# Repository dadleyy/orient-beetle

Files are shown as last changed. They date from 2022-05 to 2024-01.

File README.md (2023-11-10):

# Orient-Beetle

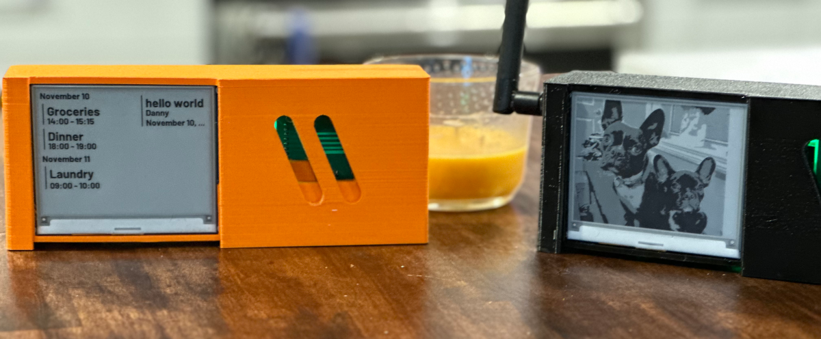
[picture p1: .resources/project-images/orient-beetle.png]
orient-beetle


A project that incorporates a wifi-enabled microcontroller, an e-ink display and some nice
RGB LEDs.

For general platform architecture documentation, see [`.docs/architecture.md`][arch].

For the hardware bill of materials, see [`.docs/hardware.md`][bom]

## Beetle PIO (Firmware)

The firmware for the application lives in [`src/beetle-pio`][fm-rd] and can be compiled
using the [platformIO cli][pio]. 

### Environment Setup: Redis Environment Variables

The firmware relies on compile-time configuration information to determine what server,
port, and authentication information to use when establishing it's secure connection to
your redis instance. The most straightforward way to set this up is to define a `.env`
file at the root of the `beetle-io` platformio application:

```
$ cat ./src/beetle-io/.env

REDIS_PORT=1234
REDIS_HOST="my-redis.my-host.com"
REDIS_AUTH_USERNAME="orient-beetle-device-id-consumer"
REDIS_AUTH_PASSWORD="1bc2ad"
```

This file is read by the [`extra_scripts`][extra_scripts] entry [`load_env.py`][lenv] and will
automatically attempt to set the correct `-DREDIS_HOST`, `-DREDIS_PORT`, and auth compiler flags.

The values of the `REDIS_AUTH_USERNAME` and `REDIS_AUTH_PASSWORD` values
require successfully "provisioning" your environment (more on this in the
[`srv` documentation](#beetle-srv-(web-backend)) below).

### Environment Setup: Redis Host CA Certificate

In order for the esp32 module to connect over tls to your redis host, you will need
to download the root ca certificate for the host and save it to:

```
src/beetle-pio/embeds/redis_host_root_ca.pem
```

The contents of this file are loaded into flash memory via the
`board_build.embed_txtfiles` setting defined in the project's `platform.ini`
file.

_For more information on how to prepare the ssl/tls components for our redis
connection, refer to [`.docs/redis-help.md`](.docs/redis-help.md)_.

### Compiling With `pio`

Once your environment and certificate file have been prepared, the firmware can
be compiled from the `beetle-pio` directory:

```
$ cd src/beetle-pio
$ pio run -t upload             <- will attempt to compile + upload to device
$ pio run -t upload -e release  <- builds without Serial logs
```

### Hardware & Documentation

For a list of harware involved and other documentation, see [`.docs/README.md`](/.docs/README.md).

#### Troubleshooting with `src/beetle-pio-tls-tester`

It can be ticky to know which certificate is required for a valid connection over tls with
your hosted redis provider. To help validate your certificate, the
[`src/beetle-pio-tls-tester`](./src/beetle-pio-tls-tester) directory contains a platformio
project can can be flashed onto your ESP32 to verify.

This project uses a very similar to configuration to the main `beetle-pio` project; you are
expected to provide both a `.env` file and `embeds/redis_host_root_ca.pem` file. If your
certificate file is valid, you should see something like:

```
[  4353][V][ssl_client.cpp:59] start_ssl_client(): Free internal heap before TLS 225035
[  4361][V][ssl_client.cpp:65] start_ssl_client(): Starting socket
[  4707][V][ssl_client.cpp:141] start_ssl_client(): Seeding the random number generator
[  4709][V][ssl_client.cpp:150] start_ssl_client(): Setting up the SSL/TLS structure...
[  4712][V][ssl_client.cpp:166] start_ssl_client(): Loading CA cert
[  4782][V][ssl_client.cpp:234] start_ssl_client(): Setting hostname for TLS session...
[  4783][V][ssl_client.cpp:249] start_ssl_client(): Performing the SSL/TLS handshake...
[  6214][V][ssl_client.cpp:270] start_ssl_client(): Verifying peer X.509 certificate...
[  6215][V][ssl_client.cpp:279] start_ssl_client(): Certificate verified.
[  6218][V][ssl_client.cpp:294] start_ssl_client(): Free internal heap after TLS 177751
[  6226][D][main.cpp:26] loop(): connection result: 1
[  7231][D][main.cpp:18] loop(): connected: 1
```

This assumes you have compiled and uploaded via `pio`:

```
$ pio run -t upload
$ screen /dev/ttyUSB0 115200
```

----

## Beetle SRV (Web Backend)

There are several rust exectuables that live in the [`srv/beetle-srv`](./src/beetle-srv/README.md)
directory. This includes the http api, a dirty little cli for troubleshooting, and a background worker
responsible for applying logic based on device connections. These applications generally require
an `env.toml` file with the various secrets that will be used for redis, mongo, etc... An example 
file can be seen at [`src/beetle-src/env.example.toml`](src/beetle-srv/env.example.toml)

For more detailed instructions for hosting your own instance, refer to [`.docs/hosting.md`](./.docs/hosting.md).

### Creating Redis ACL for all devices

As part of provisioning your environment, you will need to create the appropriate redis acl entry that
will be flashed onto all devices and should only be able to `pop` ids off our registrar index:

```
$ cd src/beetle-srv
$ cargo run cli provision orient-beetle-id-consumer abc1234
```

----

## Beetle UI (Web Frontend)

The web ui for this project can be found in the [`src/beetle-ui`](./src/beetle-ui/README.md) directory.

----

## Miscellaneous Tools

1. [WiFi Configuration HTML Generator][wchgen] - This tiny rust application is used to generate the
contents of the `src/beetle-pio/embed/index.html` file from an `index.html` file input.

--- 

## Nice Third Party Providers for Services Used At Runtime

- redis @ [upstash](https://upstash.com/) - supports tls _and_ `ACL` command management. not really free.
- mongo @ [cloud.mongodb.com](https://cloud.mongodb.com) - has a free tier for hosted mongodb databases/clusters.
- oauth @ [auth0](https://manage.auth0.com) - has a free tier for managing your login page.

---

This project was named by combining the name of the development board (fire<i>beetle</i>) with the name of
the manufacturer of the display being used (_orient_ displays).

[pio]: https://docs.platformio.org/en/stable/core/index.html
[dotenv]: https://github.com/ohmyzsh/ohmyzsh/blob/master/plugins/dotenv/dotenv.plugin.zsh
[wchgen]: ./tools/wchgen/README.md
[extra_scripts]: https://docs.platformio.org/en/latest/scripting/actions.html
[lenv]: ./src/beetle-pio/load_env.py
[fm-rd]: ./src/beetle-pio/README.md
[arch]: ./.docs/architecture.md
[bom]: ./.docs/hardware.md

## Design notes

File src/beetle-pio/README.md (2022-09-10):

# Orient-Beetle Firmware

This is the [platformio]-based project with the source code for the firmware
that runs on the [firebeetle] microcontroller board.

## Generating Fonts

The fonts used by the firmware have been "compiled" down from `.ttf` files
into lvgl-specific header files using the [fontconverter] tool provided by
the maintainers of that framework.

A mapping of characters to icons can be found in the [`mapping.md`][mm] file
located in the `.resources/Glyphter-font` directory at the root of this repo.
 
## Helpful Links

1. [ESP32 Arduino Core][esp32-arduino-core]
1. [lvgl][lvgl]
2. [`lib/README`](./lib/README.md)
2. [`include/README`](./include/README.md)

[← README](../../README.md)

[platformio]: https://platformio.org
[firebeetle]: https://www.dfrobot.com/product-2195.html
[esp32-arduino-core]: https://github.com/espressif/arduino-esp32/tree/master/libraries
[mm]: ../../.resources/Glyphter-font/mapping.md
[fontconverter]: https://lvgl.io/tools/fontconverter
[lvgl]: https://docs.lvgl.io/8/

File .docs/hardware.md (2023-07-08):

### Rev. 2

| name | manufacturer | price | docs |
| ---- | ---- | ---- | --- |
| Xiao ESP32C3 | Seeed Studios | [~$5 (@ digikey.com)][xiao-digi] | [wiki][xiao-wiki] |
| 4.2" E-Ink Display | Orient Displays | [~$35 (@ amazon.com)][xiao-display-amzn] | |
| ws2812b led | | [~$20 (@ amazon.com)][led-amzn] (partial strip use) | |
| lipo battery | | [4 pack ~$40 (@ amazon.com)][lip-amzn] (~$10 each) |
| antenna | | [2 pack ~$9 (@ amazon.com)][antenna-amzn] (~$4.50 each) |

> Note: the rev. 2 pcb "shield" schematic and board files can be found in the [`/hardware`](../hardware)
> directory. These were created in Eagle.

#### Xiao ESP32-C3 Soldering

The xiao-esp32c3 does include a battery charge chip, but the connections are not exposed as pin
through holes; they are surface pads on the bottom of the chip, marked by the `BAT` label:

| :camera: |
| --- |
|  |

To use the lipo battery, JST cables like [these (amazon link)][jst-amzn] can be soldered to them,
making sure to match the polarity correctly (typically, red to `+`, black to `-`).

---

### Rev. 1*

| name | manufacturer | price | docs |
| ---- | ---- | ---- | --- |
| Firebeetle 2 | DFRobot | [~$8 (@ digikey.com)][beetle] | [wiki][beetle-wiki] |
| 2.4" TFT Display | Orient Displays | [~$14 (@ digikey.com)][display] | [datasheet][display-sheet] |
| VCNL4010 Sensor | Adafruit | [~$8 (@ adafruit.com)][sensor] | [wiki][sensor-wiki] |

> The architecure was overhauled in May 2023 (`v0.1.0`), with the responsibility of rendering messages
> moved from the device into the `srv-*` related appications. The firmware has not been updated to 
> reflect these changes.

##### Rev 1: Pinout

| display pin | firebeetle pin | notes |
| ---- | --- | --- |
| GND | GND | |
| VIN | 3V3 | |
| SCL | SCK |  |
| SDA | MOSI | |
| RST | D12 | this is pin `4` when using `digitalWrite(...)` |
| DC | D11 | this is pin `16` when using `digitalWrite(...)` |
| CS | D10 | this is pin `7` when using `digitalWrite(...)` |
| BLK | D7 | this is pin `13` when using `digitalWrite(...)` |

---

[← README](./README.md)

[display]: https://www.digikey.com/en/products/detail/orient-display/AFL240320A0-2-4N12NTM-ANO/13916615
[beetle]: https://www.digikey.com/en/products/detail/dfrobot/DFR0654/13978504
[beetle-wiki]: https://wiki.dfrobot.com/FireBeetle_Board_ESP32_E_SKU_DFR0654
[display-sheet]: https://www.orientdisplay.com/wp-content/uploads/2021/02/AFL240320A0-2.4N12NTM-ANO.pdf
[sensor]: https://www.adafruit.com/product/466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
[sensor-wiki]: https://learn.adafruit.com/using-vcnl4010-proximity-sensor
[xiao-digi]: https://www.digikey.com/en/products/detail/seeed-technology-co-ltd/113991054/16652880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
[xiao-wiki]: https://www.seeedstudio.com/Seeed-XIAO-ESP32C3-p-5431.html
[xiao-display-amzn]: https://www.amazon.com/dp/B074NR1SW2
[led-amzn]: https://www.amazon.com/gp/product/B088BPGMXB
[lip-amzn]: https://www.amazon.com/gp/product/B095YB8CJK
[antenna-amzn]: https://www.amazon.com/gp/product/B01KBU61S8
[jst-amzn]: https://www.amazon.com/dp/B07FP2FCYC

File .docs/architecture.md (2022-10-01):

# General Platform Architecture

At a high level, the architecture of the platform is based on four components - a web backend,
a web frontend, and the individual devices, with a redis database being leveraged as a message
broker and authentication system for the devices:

general-architecture

### Device Authorization

In order for devices to receive messages, they must first authenticate with the redis service,
which is what we're using to act as a message broker. This authentication scheme is handled by
using redis ACL entries, with a global provisioning ACL burned into devices during firmware
flashing.

```mermaid
sequenceDiagram
    Embedded Device->>Redis: AUTH <burn-in-acl>
    Redis-->>Embedded Device: +OK
    Embedded Device->>Redis: LPOP available_ids
    Redis-->>Embedded Device: 4af2bbd1
    Embedded Device->>Redis: AUTH 4af2bbd1
    Redis-->>Embedded Device: +OK
    note over Embedded Device,Redis: authorized for LPOP
    loop Every Second
        Embedded Device->>Redis: LPOP messages:4af2bbd1
        Redis-->>Embedded Device: <state-message>
    end
```

[← README](../../README.md)

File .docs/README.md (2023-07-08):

### Documentation

1. [Architecture](./architecture.md) - A general outline of the platform architecture.
1. [Hardware Information](./hardware.md) - Bill of materials + general hardware preparation.
1. [Hosting Information](./hosting.md) - Instructions for hosting the rust cloud platform.
1. [Redis Configuration](./redis-help.md) -  Redis FAQ for the `beetle-pio` firmware.

[← README](../README.md)

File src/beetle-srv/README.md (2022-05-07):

## Beetle SRV

This directory contains the [rust] applications for this project.

[← README](../../README.md)

[rust]: https://www.rust-lang.org/

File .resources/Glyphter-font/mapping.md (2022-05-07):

### Font → Icon Mapping

| Character | Icon |
| --- | --- |
| `A` | up arrow |
| `B` | right arrow |
| `C` | down arrow |
| `D` | left arrow |
| `E` | right chevron |
| `F` | info i |
| `G` | info i triangle |
| `H` | thumbtack |
| `I` | checkmark |
| `J` | wifi |
| `K` | person |
| `L` | star |
| `M` | `@` sign |
| `N` | message bubble |
| `O` | plane |
| `P` | calendar |

[← README](../../README.md)

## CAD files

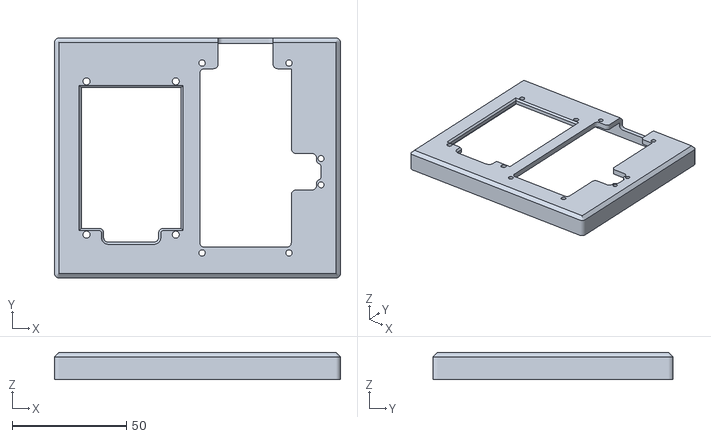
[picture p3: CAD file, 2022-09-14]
hardware/stl/main-case-body.stl
125.0 x 105.0 x 12.0

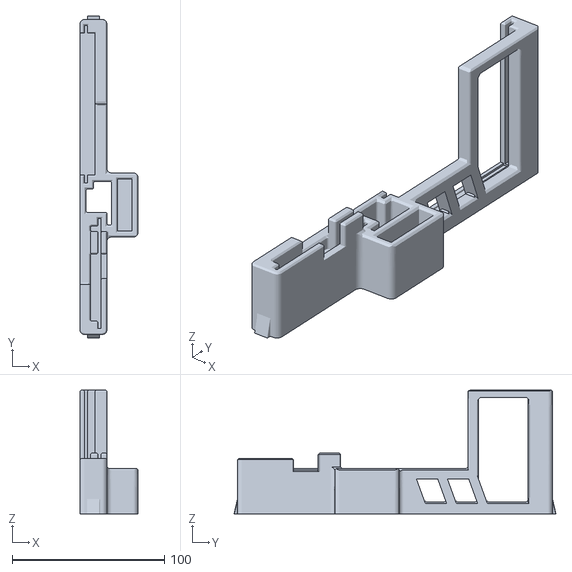
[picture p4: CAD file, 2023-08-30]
hardware/stl/xiao-insert-v85.stl
38.1 x 211.6 x 81.5

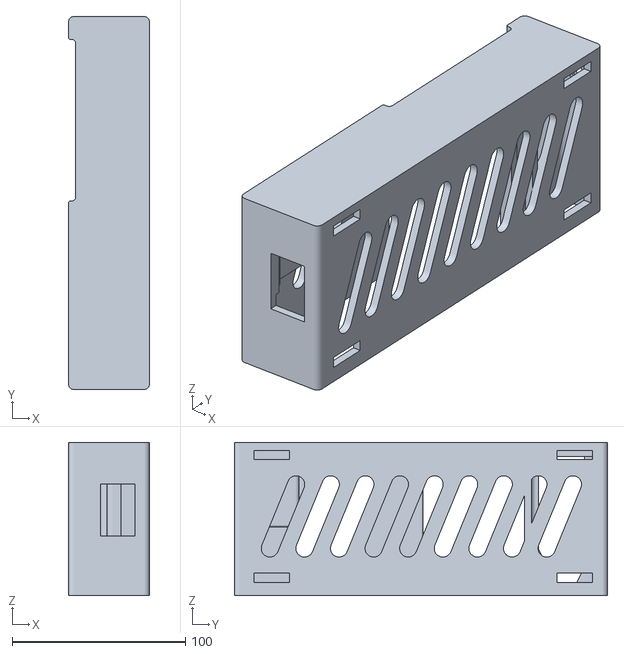
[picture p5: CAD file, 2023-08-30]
hardware/stl/xiao-outer-v85.stl
46.7 x 215.6 x 88.5

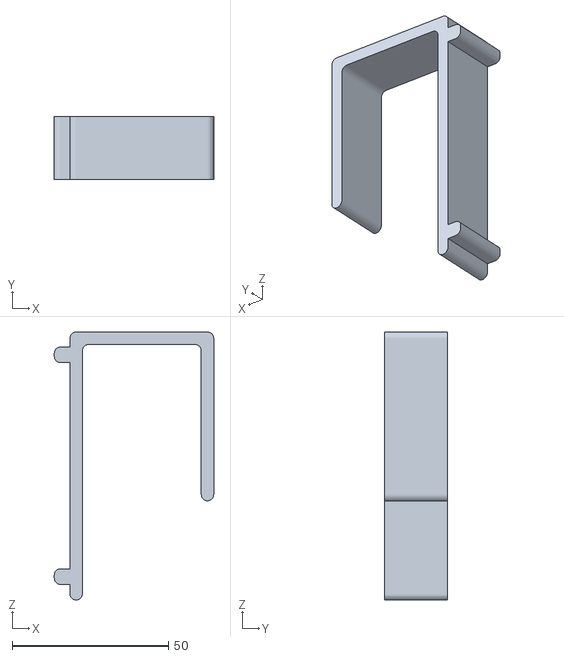
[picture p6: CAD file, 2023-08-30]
hardware/stl/xiao-peg-v85.stl
51.0 x 20.0 x 85.7

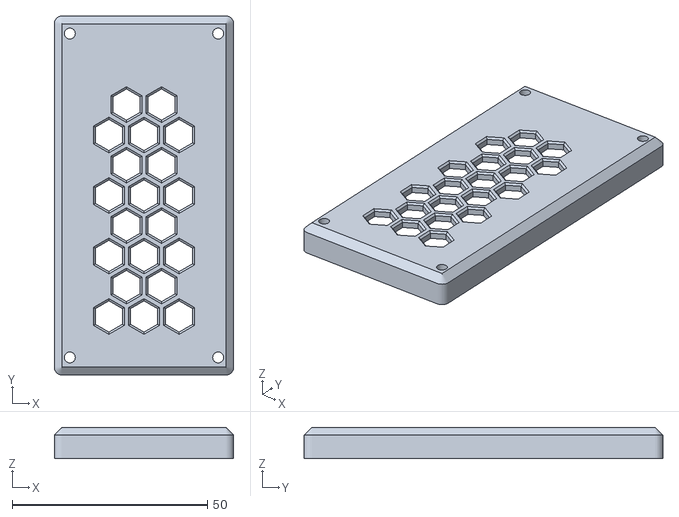
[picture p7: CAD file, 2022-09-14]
hardware/stl/beetle-expansion.stl
46.0 x 92.0 x 8.00

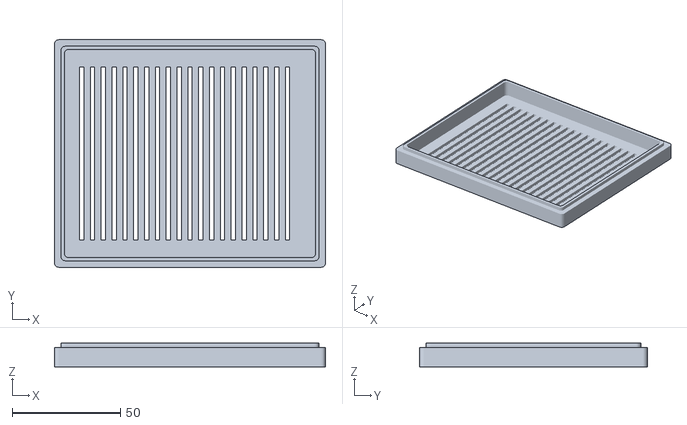
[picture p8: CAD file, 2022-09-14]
hardware/stl/case-bottom.stl
125.0 x 105.0 x 11.0

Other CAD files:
hardware/firebeetle-legacy/fusion-360/orient-beetle-screen-case-v2 v14.f3d
hardware/fusion-360/orient-beetle-screen-case-v2 v14.f3d

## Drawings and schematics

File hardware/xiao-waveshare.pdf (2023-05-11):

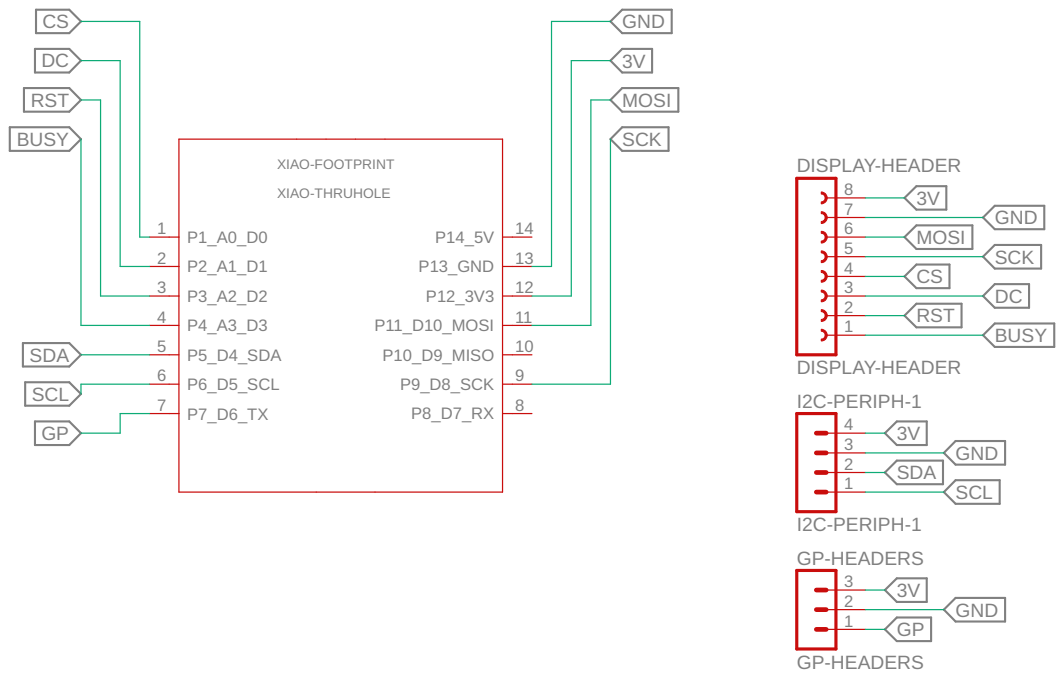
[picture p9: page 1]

Document Number: | REV:

Date: 5/11/23 10:57 AM | Sheet: 1/1

5/11/23 10:58 AM f=0.93 /Users/danny.hadley/src/dadleyy/orient-beetle/hardware/xiao-waveshare.sch (Sheet: 1/1)

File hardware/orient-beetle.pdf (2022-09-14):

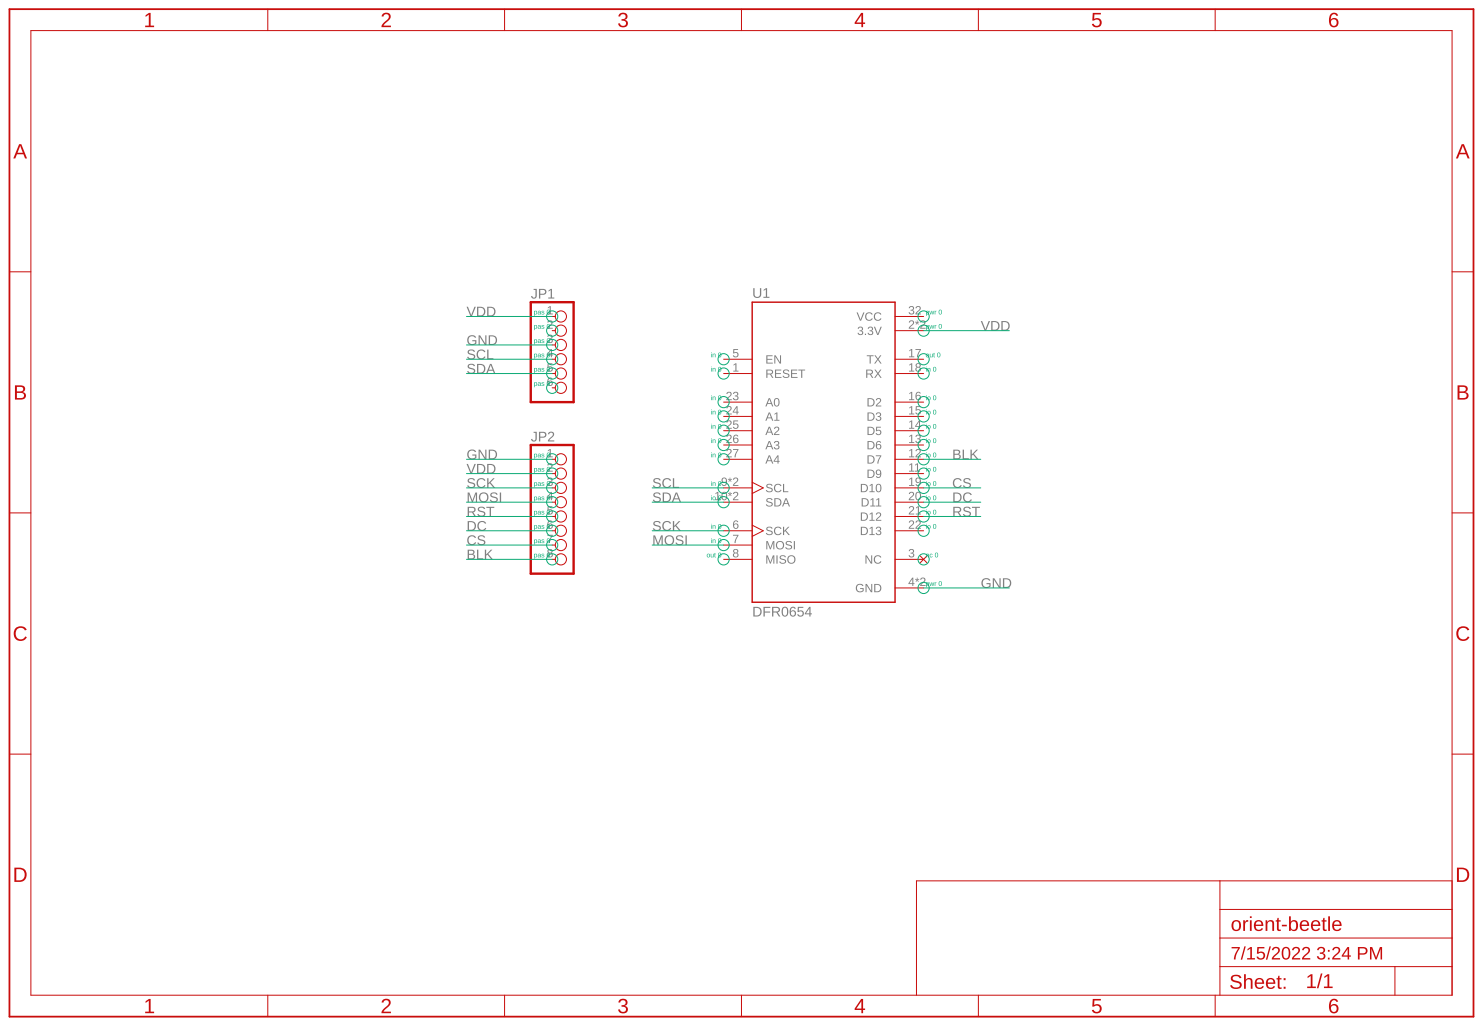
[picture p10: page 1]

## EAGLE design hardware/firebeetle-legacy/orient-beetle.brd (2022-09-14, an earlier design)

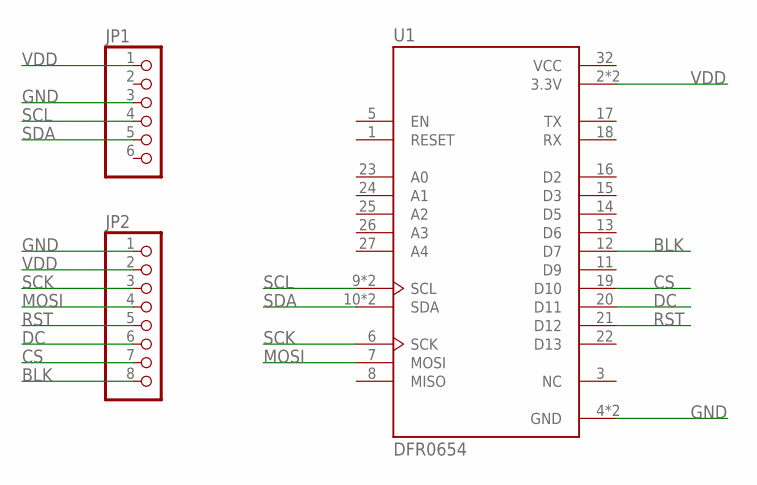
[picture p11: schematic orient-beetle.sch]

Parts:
JP1: PINHD-1X6; 1X06
JP2: PINHD-1X8; 1X08
U1: DFR0654; MODULE_DFR0654

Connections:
BLK: JP2.8, U1.12 (D7)
CS: JP2.7, U1.19 (D10)
DC: JP2.6, U1.20 (D11)
GND: JP1.3, JP2.1, U1.4 (GND), U1.30 (GND)
MOSI: JP2.4, U1.7 (MOSI)
RST: JP2.5, U1.21 (D12)
SCK: JP2.3, U1.6 (SCK)
SCL: JP1.4, U1.9 (SCL), U1.29 (SCL)
SDA: JP1.5, U1.10 (SDA), U1.28 (SDA)
VCC: U1.32 (VCC)
VDD: JP1.1, JP2.2, U1.2 (3.3V), U1.31 (3.3V)

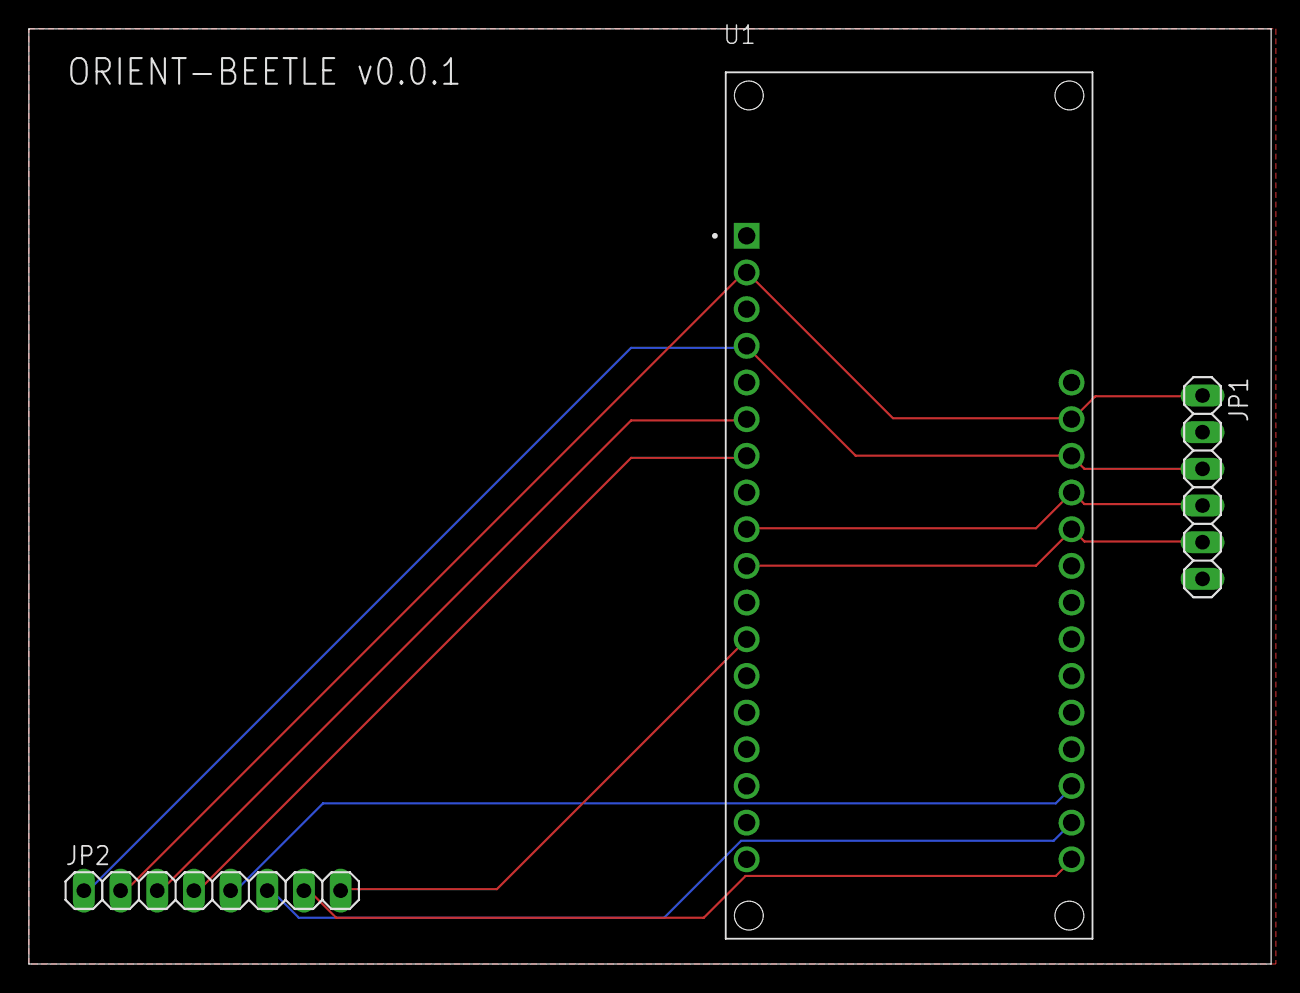
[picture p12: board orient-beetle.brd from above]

Board: 2 copper layers, 86.0 x 64.8 mm, 3 parts (0 on the bottom side), 10 nets.

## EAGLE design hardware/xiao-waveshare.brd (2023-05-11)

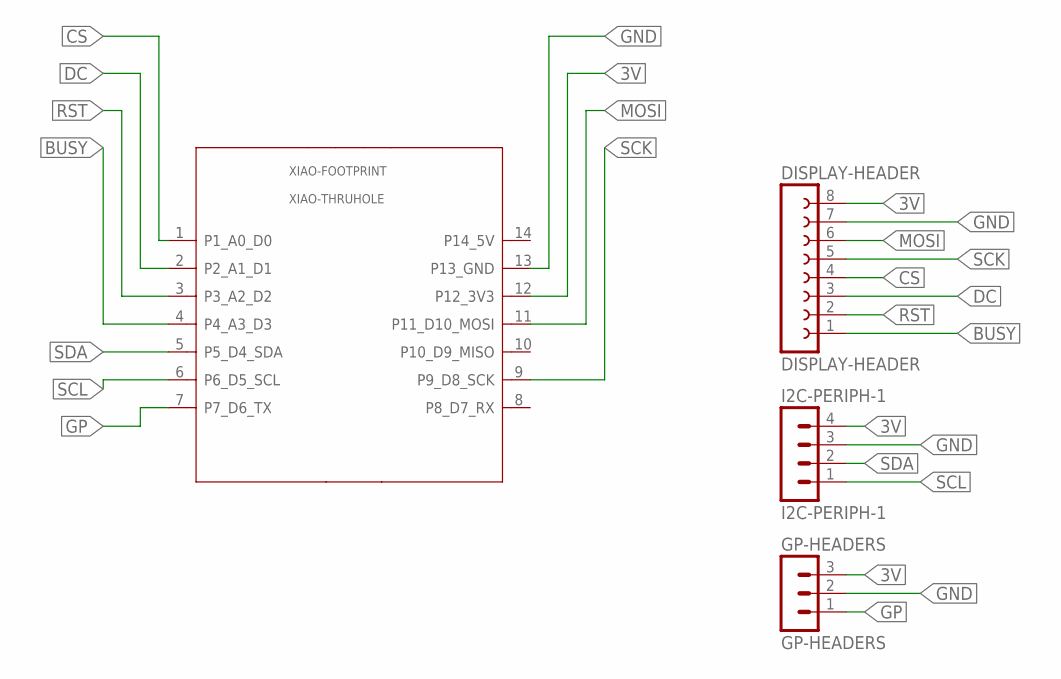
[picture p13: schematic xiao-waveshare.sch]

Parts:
DISPLAY-HEADER: DISPLAY-HEADER; FE08
GP-HEADERS: GP-HEADERS; MA03-1
I2C-PERIPH-1: I2C-PERIPH-1; MA04-1
XIAO-FOOTPRINT: XIAO-THRUHOLE; XIAO-GENERIC-THRUHOLE-MODULE14P-2.54-21X17.8MM

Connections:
3V: DISPLAY-HEADER.8, GP-HEADERS.3, I2C-PERIPH-1.4, XIAO-FOOTPRINT.12 (P12_3V3)
BUSY: DISPLAY-HEADER.1, XIAO-FOOTPRINT.4 (P4_A3_D3)
CS: DISPLAY-HEADER.4, XIAO-FOOTPRINT.1 (P1_A0_D0)
DC: DISPLAY-HEADER.3, XIAO-FOOTPRINT.2 (P2_A1_D1)
GND: DISPLAY-HEADER.7, GP-HEADERS.2, I2C-PERIPH-1.3, XIAO-FOOTPRINT.13 (P13_GND)
GP: GP-HEADERS.1, XIAO-FOOTPRINT.7 (P7_D6_TX)
MOSI: DISPLAY-HEADER.6, XIAO-FOOTPRINT.11 (P11_D10_MOSI)
RST: DISPLAY-HEADER.2, XIAO-FOOTPRINT.3 (P3_A2_D2)
SCK: DISPLAY-HEADER.5, XIAO-FOOTPRINT.9 (P9_D8_SCK)
SCL: I2C-PERIPH-1.1, XIAO-FOOTPRINT.6 (P6_D5_SCL)
SDA: I2C-PERIPH-1.2, XIAO-FOOTPRINT.5 (P5_D4_SDA)

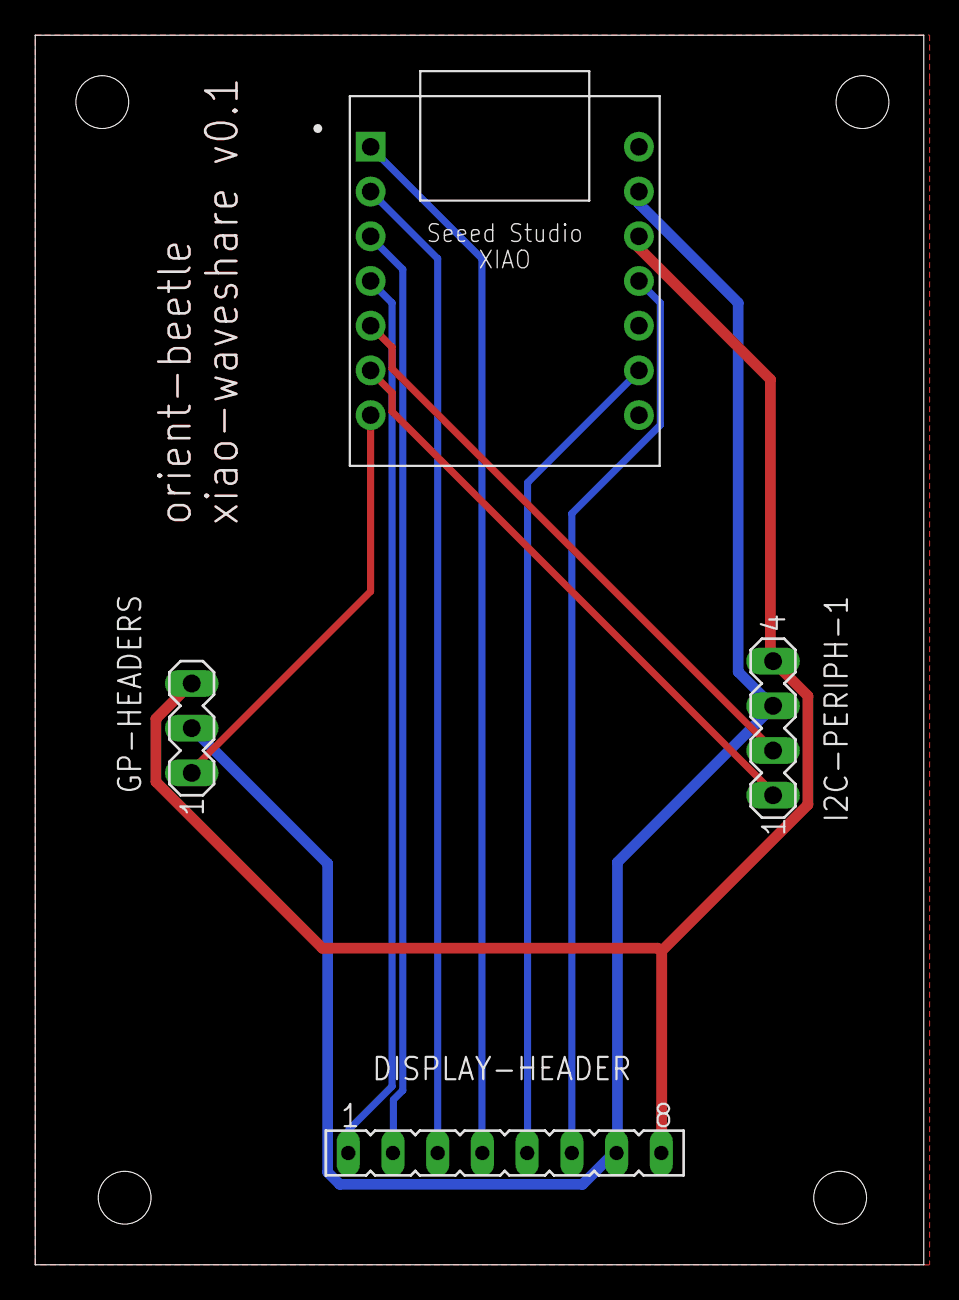
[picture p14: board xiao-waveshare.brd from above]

Board: 2 copper layers, 50.5 x 69.8 mm, 4 parts (0 on the bottom side), 11 nets.

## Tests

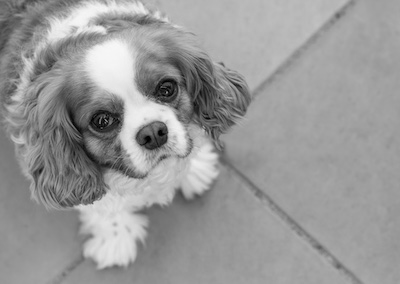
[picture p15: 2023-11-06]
tools/beetle-pio-image-tester/fixtures/dog.png

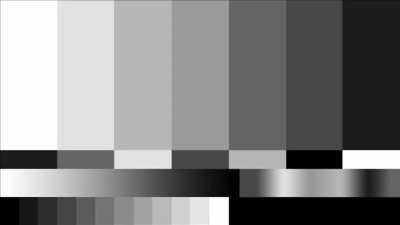
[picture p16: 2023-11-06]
tools/beetle-pio-image-tester/fixtures/gray-tester.png

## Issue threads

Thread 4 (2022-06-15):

general todo

dadleyy, 2022-06-15:
could break each one of these into it's own issue, probably

- [ ] message encryption at rest
- [ ] reconcile source-of-truth for latest connection state (e.g - no `ob:a` redis hash - use mongo instead)
- [ ] more interesting device rendering
- [ ] multi user ownership/permission modeling
- [ ] better/stronger device identifiers
- [ ] document hardware production

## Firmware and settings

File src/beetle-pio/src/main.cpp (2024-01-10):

#ifdef XIAO
#ifdef FIREBEETLE
static_assert(1 = 0,
              "Error! Either xiao OR firebeetle must be selected, not both.");
#endif
#endif
#ifndef XIAO
#ifndef FIREBEETLE
static_assert(1 = 0,
              "Error! Either xiao OR firebeetle must be selected, not both.");
#endif
#endif

#include <Arduino.h>

#include "esp32-hal-log.h"

#ifdef XIAO
#include <SPI.h>
#include <Wire.h>
#endif

#ifdef FIREBEETLE
#include "Adafruit_VCNL4010.h"
#include "firebeetle-rendering.hpp"
#endif
#ifdef XIAO
#include "xiao-lighting.hpp"
#include "xiao-rendering.hpp"
lighting::Lighting lights;
#endif

// Internal libraries
#include "microtim.hpp"
#include "redis-events.hpp"
#include "wifi-events.hpp"

// Configuration files
#include "engine.hpp"
#include "redis_config.hpp"
#include "state.hpp"
#include "wifi_config.hpp"

extern const char* ap_ssid;
extern const char* ap_password;

extern const char* redis_host;
extern const uint32_t redis_port;

extern const char* redis_auth_username;
extern const char* redis_auth_password;

// TODO: explore constructing the wifi + redis managers here. Dealing with the
// copy
// and/or movement semantics of their constructors is out of scope for now.
Engine eng(std::make_pair(ap_ssid, ap_password),
           std::make_shared<redisevents::RedisConfig>(
               redis_host, redis_port,
               std::make_pair(redis_auth_username, redis_auth_password)));

states::State state = states::Unknown{};

#ifdef FIREBEETLE
Adafruit_VCNL4010 vcnl;
#endif

#ifndef RELEASE
microtim::MicroTimer _debug_timer(5000);
#endif

// DEPRECATED: Proximity sensors were removed on the hardware migration to using
// e-ink displays with the xiao esp32c3.
#ifndef DISABLE_PROXIMITY
microtim::MicroTimer _prox_timer(5000);
bool _prox_state = true;
bool prox_ready = false;
#endif

uint32_t last_frame = 0;
bool failed = false;

void setup(void) {
#ifdef XIAO
  pinMode(XIAO_NEOPIXEL_PIN, OUTPUT);
#endif

#ifndef RELEASE
  Serial.begin(115200);
#endif

  unsigned char i = 0;

  while (i < 12) {
#ifdef XIAO
    lights.boot(i);
#endif
    delay(500);
    i += 1;
  }

  failed = display_init();

#ifndef DISABLE_PROXIMITY
  if (vcnl.begin()) {
    log_d("vcnl proximity sensor detected!");
    prox_ready = true;
  } else {
    log_e("[warning] no vcnl proximity sensor detected!");
    failed = true;
  }
#else
  log_e("[notice] proximity functionality disabled at compile time");
#endif

  eng.begin();
}

void loop(void) {
  auto now = millis();

#ifndef DISABLE_PROXIMITY
  uint16_t prox = prox_ready ? vcnl.readProximity() : 0;
  // Proximity sensor LED on/off.
  if (prox_ready) {
    if (prox > 6000) {
      _prox_timer = std::move(microtim::MicroTimer(5000));

      if (!_prox_state) {
        log_d("turning on LED");
        digitalWrite(LCD_PIN_NUM_BCKL, HIGH);
      }

      _prox_state = true;
    }

    if (_prox_timer.update(now) == 1) {
      if (_prox_state) {
        log_d("turning off LED");
        digitalWrite(LCD_PIN_NUM_BCKL, LOW);
      }
      _prox_state = false;
    }
  }
#endif

#ifndef RELEASE
  bool print_debug_info = _debug_timer.update(now) == 1;
  if (print_debug_info) {
#ifndef DISABLE_PROXIMITY
    log_d("proximity (enabled %d): %d", prox_ready, prox);
#endif
    log_d("free memory before update: %d (max %d)", ESP.getFreeHeap(),
          ESP.getMaxAllocHeap());
  }
#endif

  // Apply updates.
  state = eng.update(std::move(state), now);

#ifdef XIAO
  lights = std::move(std::move(lights).update(state));
#endif

  if (std::get_if<states::HoldingUpdate>(&state)) {
    states::HoldingUpdate* working_state =
        std::get_if<states::HoldingUpdate>(&state);
    display_render_state(working_state, last_frame);
  } else {
    display_render_unknown(last_frame);
  }

  state = states::Idle{};

  last_frame = now;
#ifndef RELEASE
  if (print_debug_info) {
    log_d("free memory after update: %d (max %d)", ESP.getFreeHeap(),
          ESP.getMaxAllocHeap());
  }
#endif
}

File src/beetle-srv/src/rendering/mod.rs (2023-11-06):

//! Note: the actually rendering here - the process of generating a bitmap image to send to the
//! device based on some data structure - could be way more advanced than it is currently. The
//! `imageproc` crate is very nice for the time being, but it may not support the wild kinds of
//! rendering that this would want to support in the future.

use serde::{Deserialize, Serialize};
use std::io;

/// Defines all of the binary-included fonts available.
mod fonts;
pub use fonts::FontSelection;

/// Defines layout constants like padding and margins.
mod constants;

/// Defines the components that can be used within a layout.
pub mod components;
pub use components::{OptionalBoundingBox, StylizedMessage};

/// The rendering queue module contains the central business logic for taking a layout and adding
/// it to the queue of things to be rendered and sent to devices.
pub(crate) mod queue;
pub use queue::{Queue, QueuedRenderAuthority};

/// The renderer itself is responsible for periodically popping from the queue and doing the
/// things.
mod renderer;
pub use renderer::run;

/// The types of things that a split can contain.
#[derive(Debug, Clone, Serialize, Deserialize)]
#[serde(rename_all = "snake_case", tag = "beetle:kind", content = "beetle:content")]
pub enum SplitContents<S> {
  /// A list of messages.
  Messages(Vec<components::StylizedMessage<S>>),

  /// Embeds a qr code onto the split side.
  Scannable(components::Scannable<S>),
}

/// An layout that has content on the left and right.
#[derive(Debug, Clone, Serialize, Deserialize)]
#[serde(rename_all = "snake_case")]
pub struct SplitLayout<S> {
  /// What gets rendered on the left.
  pub left: SplitContents<S>,

  /// What gets rendered on the right.
  pub right: SplitContents<S>,

  /// A 0-100 value of how much space the _left_ split should take.
  pub ratio: u8,
}

/// The render layout represents the various kinds of layouts that can be rendered into a
/// rasterized image and sent to the embedded devices.
#[derive(Debug, Clone, Serialize, Deserialize)]
#[serde(rename_all = "snake_case", tag = "beetle:kind", content = "beetle:content")]
pub enum RenderLayout<S> {
  /// Clears the screen.
  Clear,

  /// Holds a location on disc to raw image data.
  Raw(S),

  /// A single styleized message. Will be rendered in the middle of the display being rasterized
  /// to.
  StylizedMessage(components::StylizedMessage<S>),

  /// A layout that has content on the left, and content on the right.
  Split(SplitLayout<S>),

  /// A single qr code that will be rendered to the whole dimensions.
  Scannable(components::Scannable<S>),
}

impl<S> RenderLayout<S>
where
  S: std::convert::AsRef<str>,
{
  /// Turn this layout into a rasterized image.
  pub fn rasterize(self, dimensions: (u32, u32)) -> io::Result<Vec<u8>> {
    let mut image = image::GrayImage::new(dimensions.0, dimensions.1);

    if dimensions.0 > constants::MAX_WIDTH || dimensions.1 > constants::MAX_HEIGHT {
      return Err(io::Error::new(
        io::ErrorKind::Other,
        "dimensions exceed reasonable resolution",
      ));
    }

    // Start with an entirely white background.
    imageproc::drawing::draw_filled_rect_mut(
      &mut image,
      imageproc::rect::Rect::at(0, 0).of_size(dimensions.0, dimensions.1),
      image::Luma([255]),
    );

    match self {
      Self::Raw(location) => {
        log::info!("attempting to ctop and take grayscale of '{}'", location.as_ref());
        let mut raw_image = image::io::Reader::open(location.as_ref())
          .map_err(|error| io::Error::new(io::ErrorKind::Other, error.to_string()))?
          .decode()
          .map_err(|error| io::Error::new(io::ErrorKind::Other, error.to_string()))?;

        raw_image = raw_image.resize(dimensions.0, dimensions.1, image::imageops::FilterType::CatmullRom);
        image = raw_image.grayscale().to_luma8();
        log::info!("grayscale of '{}' successful", location.as_ref());
      }

      Self::Clear => (),
      // Scannables will replace the image buffer with one provided from the qr crate.
      Self::Scannable(scannable) => {
        image = scannable.grayscale(dimensions)?;
      }

      Self::Split(SplitLayout { left, right, ratio }) => {
        let left_max = (dimensions.0 as f32 * (ratio as f32 / 100f32)).round() as u32;

        match left {
          SplitContents::Messages(messages) => {
            let mut top = 0;
            for m in messages {
              let bounds = components::StylizedMessageBounding {
                left: 0,
                top,
                constraints: Some(components::StylizedMessageBoundingConstraints::MaxWidth(
                  left_max as i32,
                )),
              };
              let (_, h) = m.draw_within(&bounds, &mut image)?;
              top += h;
            }
          }
          _ => todo!(),
        }

        match right {
          SplitContents::Messages(messages) => {
            let mut top = 0;
            for m in messages {
              let bounds = components::StylizedMessageBounding {
                left: left_max as i32,
                top,
                constraints: Some(components::StylizedMessageBoundingConstraints::MaxWidth(
                  (dimensions.0 - left_max) as i32,
                )),
              };
              let (_, h) = m.draw_within(&bounds, &mut image)?;
              top += h;
            }
          }
          _ => todo!(),
        }
      }

      // If we're just a stylized image, draw us.
      Self::StylizedMessage(message_layout) => {
        let bounding = components::StylizedMessageBounding {
          left: 10,
          top: 10,
          constraints: None,
        };
        message_layout.draw_within(&bounding, &mut image)?;
      }
    }

    // Create our output buffer and write the image into it.
    let mut formatted_buffer = std::io::Cursor::new(Vec::with_capacity((dimensions.0 * dimensions.1) as usize));
    let encoder = image::codecs::png::PngEncoder::new_with_quality(
      &mut formatted_buffer,
      image::codecs::png::CompressionType::Best,
      image::codecs::png::FilterType::Avg,
    );
    image
      .write_with_encoder(encoder)
      .map_err(|error| io::Error::new(io::ErrorKind::Other, format!("unable to build image: {error}")))?;
    Ok(formatted_buffer.into_inner())
  }
}

/// "Rendering" commands associated with the rgb lights on a device.
#[derive(Debug, Clone, Serialize, Deserialize)]
#[serde(rename_all = "snake_case")]
pub enum LightingLayout {
  /// Requests the device to turn the lights off.
  Off,
  /// Requests the device to turn the lights on.
  On,
}
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

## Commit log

2022-04-24 wifi manager flow basic impl
2022-05-07 lots of work (#1)
    * progmem is not a thing.
    * fix indx file, loggin
    * tiny change
    * start redis abstraction
    * some redis stuff
    * more redis work, auth + pop impl
    * initial redis message handling
    [main.cpp]
2022-05-07 basic redis wiring, send message
2022-05-07 add 'registration' flow + rust registrar process
2022-05-07 device id length + cli updates
2022-05-07 driver update + display attempt
2022-05-07 ci and ui minimal (#3)
    * start ui, ci
    * quotefix
    * add build steps to client
    * add linting for kicks
    * add forgotten cargo config for link
    * ui artifact attempt
    * fix ci/ui root location
    * add some xhr to test/verify deployment
    * rm debug, oops
    * fix and remove some linkds
    * incorporate tailwind
    * try using pre-built image for cross-compile
    * use target during test
    * separate ci for non-cross build+test
    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
    [mod.rs]
2022-05-18 trudging through device ownership/claim ui
2022-05-18 more device registration work
2022-05-27 stopping point - device addition + removal
2022-06-27 start work on redis ACL security for device registration
    The goal here is going to be to have the devices flashed with redis
    authentication information that can only blpop from the specific
    `ob:r` registrar index.
    Subsequent commands with be required to have authenticated using the id
    requested, which will have been locked down by the registar using an
    additional ACL entry.
    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
2022-06-28 device-specific acls, :tada:
2022-07-10 display more device info
2022-07-14 multi message display (#1)
    * more mulit-message support
    * maybe better impl
    * update github action ls
    * update ls
    * add framework bin files
2022-08-27 more logs for redis problems (#5)
    * more logs for redis problems
    * rm comment
    [mod.rs]
2022-09-08 display driver changes (#16)
2022-09-14 merging latest hardware (#19)
    * initial screen case with sensor
    * solidify(4) too much, back to 3
    * move sensor up more
    * first pass at bottom
    * smaller holes, 0.667 of 3.6 diameter = 2.40
    * geometry nodes impl,sweet
    * geo-nodes front +back
    * geo-node increase screen hole y
    * going to print
    * back/front bottom sensor
    * shorter pcb pads, cord gap on front
    * more space for cord
    * starting v2
    * thicker, save
    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
    [beetle-expansion.stl, case-bottom.stl, main-case-body.stl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]
2023-05-11 porting to xiao + e-ink (#21)
    * [wip] starting work on xiao esp32c3 eink
    * [wip] update pio ci instructions
    * [wip] updating pio
    * [wip] update kramer, pio xiao platform set
    * [wip] image update
    * [wip] ci formatting
    * [wip] prepare subdir for artifact
    * [wip] small changes to load_env
    * [wip] minor ci improvement attempts
    * [wip] ci workflow formatting
    * [wip] ci diagnostics
    * [wip] ci: remove deprecated set-output
    * [wip] ci: fix instruction path, try boot_app0.bin again
    * [wip] ci: fix missing newline escape
    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
2023-05-11 adding latest brd+sch+pdf files for xiao+waveshare
    [xiao-waveshare.brd, xiao-waveshare.sch]
2023-05-11 update bom-related documentation
2023-05-27 add support for addressable leds (#22)
    * [wip] just having some fun with lighting
    * [wip] adding support for lighting control
    * [wip] impl lighting disable/enable fw
    * [wip] flushing out queue api again
    * [wip] adds qr code rendering support
    * [wip] cleaning up some serialization related stuff
    * [wip] updating ui to support links
    * [wip] a tiny little responsive change
    * [wip] add light toggles
    * [wip] add shortpath to registration via scannable
    * [wip] clippy lints
    * [wip] goahead with docs artifact
    * [wip] ui fix
    * [wip] publish srv docs to aws
    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
2023-07-01 authorities, schedules, histories (#23)
    [beetle-expansion.stl, case-bottom.stl, case-top.stl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]
2023-07-08 persistent device rendering state (#24)
    * types -> schema
    * starting state render percolation
    * impl push
    * flushing out more state rendering/mutation
    * cargo updates
    * move mock into separate package, start ui
    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
2023-07-08 [hw] more hardware updates (#25)
    [case-top.stl, holder-insert.stl, left-peg.stl]
2023-08-22 schema changes (#26)
    * [ci] fix workflow gpg
    * some minor cleanups for sanity. named enums
    * start migrations, maybe
    * device state migration too
    * migration cleanup
    * more cleanup
    * clear stale renders
    * adding helpful logs to migration
    * ui footer change
    * try adding some more logging for help
    * more logging
    * loggin tweaks
    * more logging
    * debug -> trace in google logs
    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
2023-08-30 [hw] adding an attempt at a little locking (#27)
    [hw] more filets
    latest stl files
    [case-top.stl, holder-insert.stl, left-peg.stl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]
2023-11-06 image upload support (#28)
    * [cargo] updates
    * try add toolchain
    * start route cleanup
    * start raw image upload + rendering
    * fileinput accept attribute
    * saving
    * ci fixes
    * more image stuff
    * warn on file size
    * larger max file limit
    * filling in initial auth
    * polish up lighting
    * rm unused lib files
    [main.cpp, mod.rs]
2024-04-02 handle wrongpass; print networks
